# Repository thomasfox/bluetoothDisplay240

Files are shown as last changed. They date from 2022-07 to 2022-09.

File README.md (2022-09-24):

# bluetoothDisplay240

A bluetooth display for displaying speed, direction and a direction deviation bar while sailing.
Speed, direction and direction deviation measurements are transmitted via bluetooth, 
e.g. by a smartphone. The sum of component prices is about 100€.

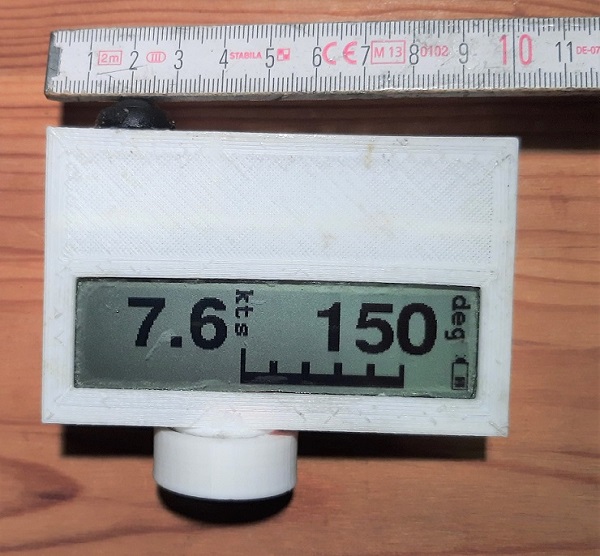
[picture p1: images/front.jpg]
Front view


This project contains
- The PCB and schematic of the circuit board in the [hardware](hardware) directory
- The code for the arduino compatible microcontroller on the circuit board in the [software](software) directory
- a Housing for 3D Printing  in the [housing](housing) directory
  (alternatively, you can use a commercial housing)

At the time of writing, material costs were approximately 100€. 
The electronics runs with 3.3V supply voltage, so it can be operated using a single LI-Ion battery.
The electronics draws about 15 mA supply current, so that with a 800 mAH battery, 
operation time is more than 50h without reloading.

## Electronics

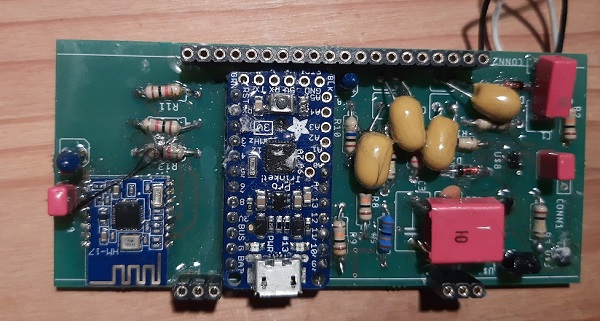
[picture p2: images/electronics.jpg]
Electronics


The main components of the ectronics are an arduino-compatible microcontroller board,
a graphical LCD Display with 240x64 pixels, and a Bluetooth Low Energy board. 
Discrete components are used for a soft-power latch and a battery watchdog. 

The quiescent current while being switched off is less than 1 μA,
so the standby-time for a 800 mA battery is only limited by the self-discharge time
of the battery.

The LCD display can be plugged in via socket rows. 
In my experience, not all socker rows provide a good contact to the LCD Display,
I had better experiences with the cheaper ones.

The arduino compatible board is soldered on using post rows, so that there is a small gap 
between the PCB and the arduino compatible board.

The press-button switch should only provide contact while pressed.
If a waterproof housing is wanted, the switch should be at least IP67 classed.

The battery charging circuit board in the BOM provides 1A of charging current.
I prefer a lower charging current of 250 mA, for which the R3 Resistor 
on the charging circuit board must be replaced by a 4k7 SMD resistor.
The charging PCB and the Arduino compatible board both use their own micro USB socket;
note that charging is not possible using the Arduino-compatible board USB socket, 
and programming is not possible using the charging board USB socket.

The current PCB design has a small flaw because the large foil condensators must lie on the PCB
rather than stand; but there is no explicit place reserved for that. 
So these condensators must be laid on top of other components, which worked for me.

The components needed are listed in the [Bill of Material (BOM)](hardware/bom.md). 
I obtained most of the components from the distributor [Reichelt](https://www.reichelt.de).
For your convenience, I have a public list there 
[https://www.reichelt.de/my/1939286](https://www.reichelt.de/my/1939286) 
containing the components marked in the BOM.
The HM 17 Bluetooth module was obtained from an ebay shop,
the non-marked resistors from a resistor assortment and the litz wire also from Reichelt.
Feel free to purchase the components where you want,
I do not earn anything if you purchase from Reichelt!

Then you need the PCB, I had mine made by [Aisler](https://aisler.net/), but again feel free to use another manufacturer.

Approximate prices at the time of writing were

| **Item** | **material** | **shipping** |
| --- | --- | --- |
| Reichelt List | 70€ | 6€ |
| HM17 | 11€ | 3€ |
| PCB | 13€ for a batch of 3 | - |

which adds up to about 100€ for one display.

### Assembly

You need a soldering iron with a small tip and soldering lead.
There are three SMD FET's on the PCB, which can be soldered with a soldering iron.
This can be a little tricky for an inexperienced solderer like me, but it worked in the end.
I'd recommend to solder the SMD FETs at the beginning, because then there is a 
Then, the film capacitors should be soldered at the end and with as much spare wire above the PCB as possible,
because they need to be bent in order to put the LCD display on top.

The battery holder should be connected to the charging board, 
which in turn should be connected to CONN1 using litz wire.
The push-Button switch should be connected to CONN2 also using litz wire.

You can consider to lacquer the board after all is finished and tested to improve water resistance. 
Be sure not to lacquer the pin rows, the lacquer tends to creep up in the pin holes.

## Software

You need to load the software onto the arduino compatible microcontroller board, e.g. using the Arduino IDE
and a micro USB cable. Make sure to select the correct board (Adafruit Trinket 3V) 
and the correct Programmer (USBtinyISP) in the Arduino IDE.

A good test is to try and upload a simple Arduino demo program (e.g. blink) onto the board 
before it is soldered in to make sure everything works as expected.

As the USB port on the microcontroller board is software-implemented,
new USB 3.0 ports typically lead to upload errors. 
The solution in my case was to use a cheap USB 2.0 hub between the PC and the microcontroller board.

To feed the display, I use my [Saillogger](https://github.com/thomasfox/saillogger) android app.

## Bluetooth Low Energy Protocol

The bluetooth low energy (BLE) transmission protocol is very simple: 
The feeding device writes the field identifier, a colon (:) and the value of the addressed field
to the one BLE characteristic offered by the device's BLE receiver. After that, the sending device needs to wait some time
(should be some 10 ms, I still need to find out how long) before sending the next value.

The field id is f1 for the velocity field, f2 for the direction field and f3 for the direction bar.
For the f1 and f2 fields, the value can be any short string containing the characters a-z, A-Z, 0-9 or .,:
(short meaning the value fits in the field's window in the display).
For the f3 field, the value needs to be an integer value between -100 and 100.
The character ';' should act as a field separator (I need to verify whether that works).

For the used characteristic, the service uuid is "0000ffe0-0000-1000-8000-00805f9b34fb"
and the characteristic uuid is "0000ffe1-0000-1000-8000-00805f9b34fb"

You can use  [Saillogger's BLE sender](https://github.com/thomasfox/saillogger/blob/master/app/src/main/java/com/github/thomasfox/saildata/sender/BleSender.java)
as a java/android code example for a bluetooth sender.

## Housing

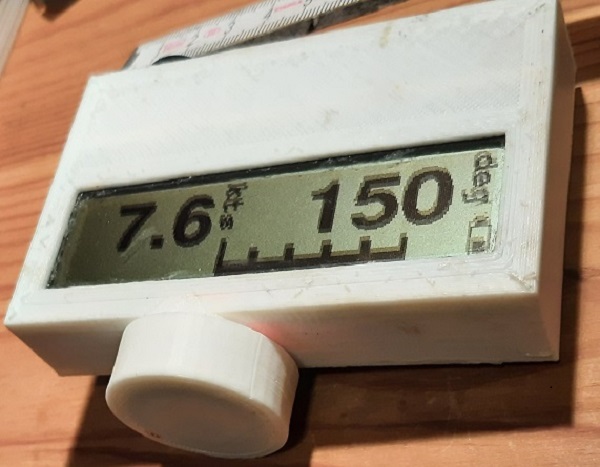
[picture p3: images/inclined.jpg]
Inclined


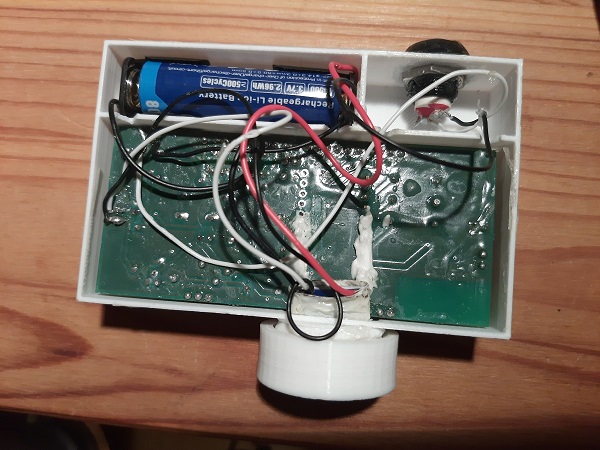
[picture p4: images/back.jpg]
Back


The Housing consists of the main housing, a lid which is glued to the main housing, 
and a screw-lid through which the two USB sockets can be accessed. 
They can be 3D printed, I used PLA as printing material.

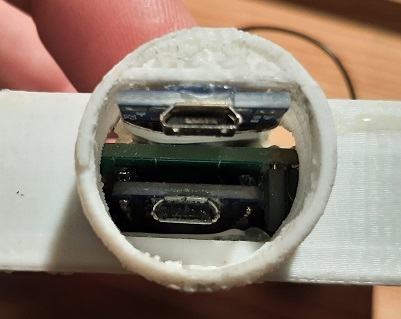
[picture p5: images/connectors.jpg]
Connectors


For a waterproof screw-lid, an o-ring is needed with an inner diameter of 20mm 
and a material diameter of 2mm.

The LCD Display is glued in the main housing, such that no water can enter between housing and Display.
Then the charging board is glued into the tube of the screw-lid, and the switch and battery holder 
are also glued into place.
Then the circuit board is connected to the LCD display, and the lid is glued an, 
also in such a way that no water can enter.

For gluing, I used pattex repair glue, which is transparent and stays flexible when cured, but any similar glue will do.

## Alternative Housing

I had some difficulties in getting my own housing really waterproof, so as an alternative
you can use a commercial housing. I used the 130x80x35mm FIBOX PC 100/35 LT Housing, 
which was available at the time of writing for €17 plus 5€ shipping from [Conrad](https://www.conrad.de).
The LCD needs to be glued to the transparent cover; I glued just the edges. 
Also a hole needs to be drilled for the push-button switch, which then also needs to be glued in.

## Questions?

Please open a [issue](../../issues) if you have any questions.

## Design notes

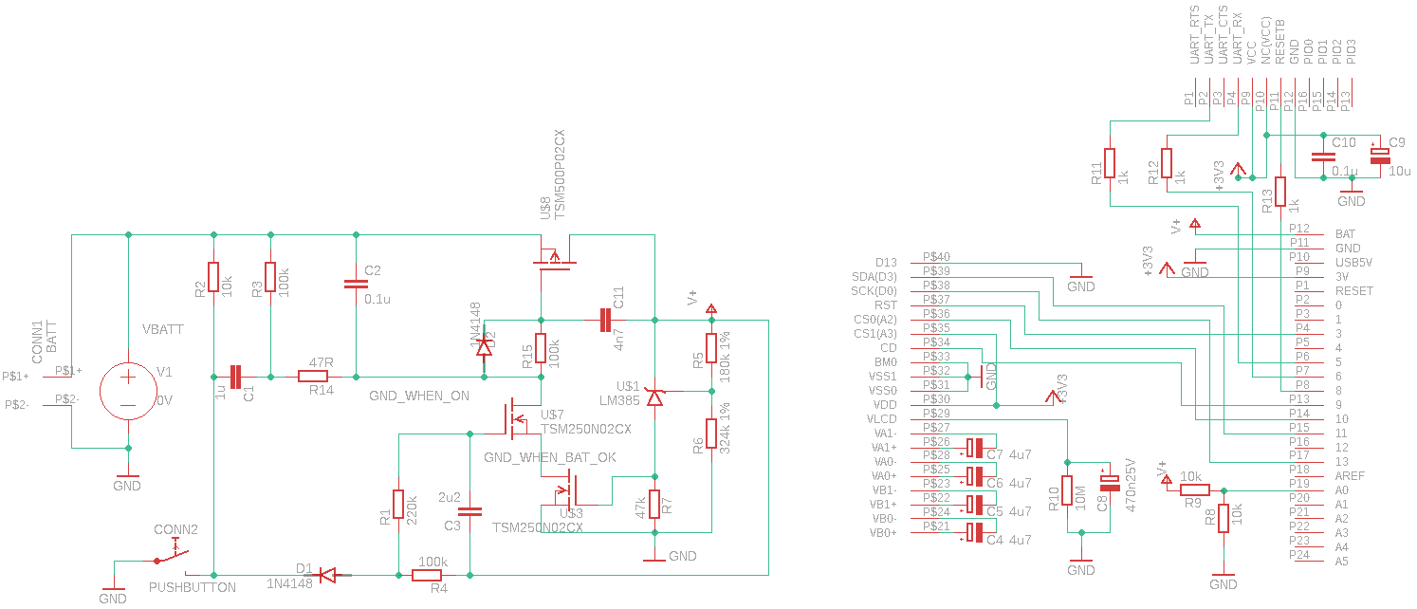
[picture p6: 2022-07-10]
hardware/BluetoothDisplay240Schematic.png

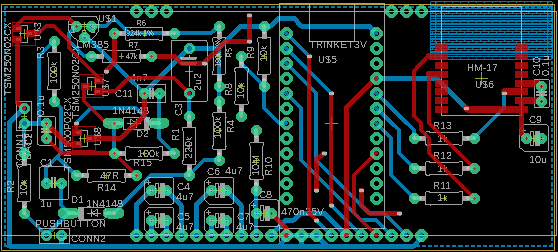
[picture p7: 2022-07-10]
hardware/BluetoothDisplay240Board.png

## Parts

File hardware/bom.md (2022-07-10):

| **Quantity** | **Value** | **Additional Info**  | **Name** | **Contained in Reichelt List** |
| ---| --- | --- | --- | --- |
| **Condensators** |
| 1 | 4n7 | 10V Ceramic | C11 | x |
| 2 | 0.1u | 10V Film | C2,C10 | x |
| 1 | 470n | 25V Tantal | C8 | x |
| 1 | 1u | 10V Film | C1 | x |
| 1 | 2.2u | 10V Film | C3 | x |
| 4 | 4.7u | 10V Tantal | C4,C5,C6,C7 | x |
| 1 | 10u | 10V Tantal | C9 | x |
| **Diodes** |
| 2 | 1N4148 | | D1,D2 | x |
| **Resisitors** |
| 1 | 47R | 1/4W 5% | R14 | |
| 3 | 1k | 1/4W 5% | R11,R12,R13 | |
| 3 | 10k | 1/4W 5% | R2,R8,R9 | |
| 1 | 47k | 1/4W 5% | R7 | |
| 3 | 100k | 1/4W 5% | R3,R4,R15 |  |
| 1 | 220k | 1/4W 5% | R1 | |
| 1 | 180k | 1/4W 1% | R5 | x |
| 1 | 324k | 1/4W 1% | R6 | x |
| 1 | 10M | 1/4W 5% | R10 | x |
| **Other** |
| 1 | | LM385Z | U$1 | x |
| 2 | | TSM250N02CX or TSM2302SMD | U$3, U$7 | x |
| 1 | | TSM500P02CX | U$8 | x |
| 1 | | DOGM240-6 | U$4 | x |
| 1 | | TRINKET3V | U$5 | x |
| 1 | | HM-17 Bluetooth Module | U$6 | |
| 1 | | Press-Button switch  | | x |
| **Charger Board** |
| 1 | | DEBO2 3.7LI 1.0A | | x |
| 1 | 4k7 | SMD Resistor 0603 100mW | | x |
| **Battery & Battery holder** |
| 1 | | Li-Ion Battery 3,7V  | | x |
| 1 | | Battery Holder | | x |
| **Socket rows** |
| 1 | | 20-Pin row 2,54mm | | x |
| 2 | | 3-Pin row 2,54mm | | x |
| **Pin rows (probably contained in Trinket3V)**  |
| 1 | | 7-pin 1row 2,54mm | | x |
| 1 | | 12-pin 1row 2,54mm  | | x |
| **wire** |
| 6 | | 15 cm litz wire | | |

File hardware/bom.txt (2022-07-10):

Part  Value       Device              Package      Description                          POPULARITY SPICEPREFIX
Condensators
1x 0.01u   C11
2x 0.1u    C2,C10
1x 470n25V C8
1x   1u    C1
1x 2.2u    C3
4x 4.7u    C4,C5,C6,C7
1x  10u    C9

Diodes
2x  1N4148 D1,D2

Resistors 1/4W 5%
1x    47R      R14
3x     1k      R11,R12,R13
3x    10k      R2,R8,R9
1x    47k      R7
3x   100k      R3,R4,R15
1x   220k      R1
1x    10M      R10

Resistors 1/4W 1%

1x   180k      R5
1x   324k      R6

U$1   LM385       LM385               TO92.PAC                                                                
U$3   TSM2302SMD  TSM2302SMD          SOT23                                                                   
U$4   DOGM240-6   DOGM240-6           LCD-DISPLAY  EA DOGM 240-6 LCD Display                                  
U$5   TRINKET3V   TRINKET3V           TRINKET3V                                                               
U$6   HM-17       HM-17               HM-17                                                                   
U$7   TSM2302SMD  TSM2302SMD          SOT23                                                                   
U$8   TSM500P02CX TSM500P02CX         SOT23                                                                   
1x Battery loader curcuit

Switches
1x Press-Button switch

Battery & Battery holder
1x Battery 3,7V
1x Battery Holder

Socket row
1 x 20Pin row
2x 6-pin row

cables
4 * 15 cm cable

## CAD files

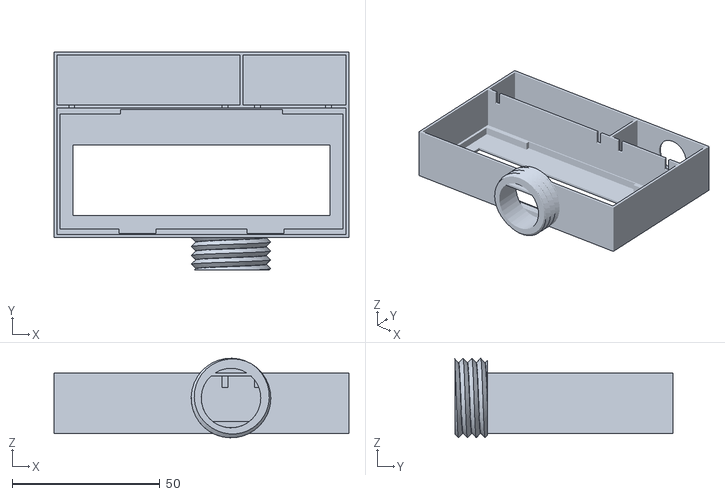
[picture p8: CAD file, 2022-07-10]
housing/SpeedDisplay240HousingMain.stl
100.0 x 74.0 x 27.0

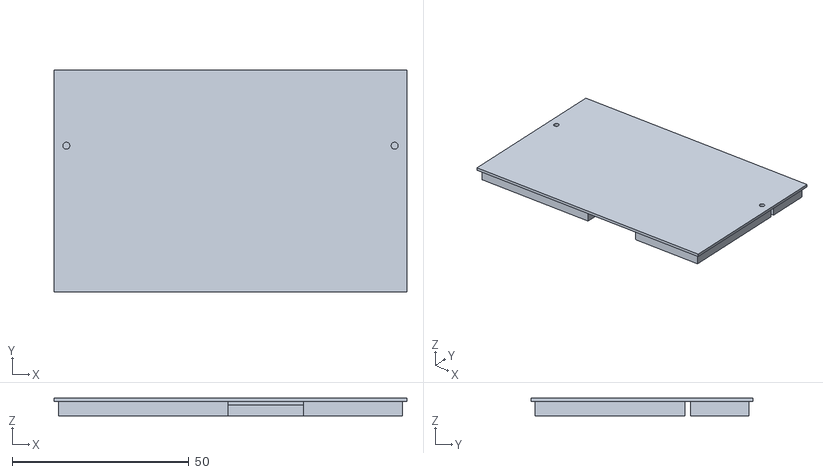
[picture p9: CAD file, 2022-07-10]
housing/SpeedDisplay240HousingLid.stl
100.0 x 63.0 x 5.00

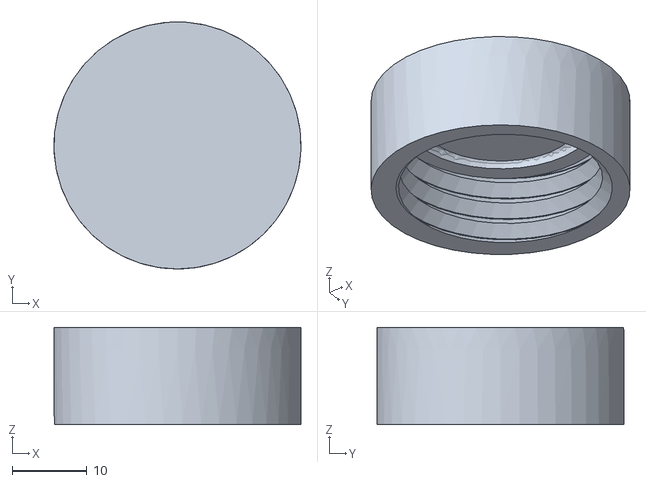
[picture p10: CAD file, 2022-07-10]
housing/SpeedDisplay240HousingScrewCap.stl
33.0 x 33.0 x 13.0

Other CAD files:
housing/SpeedDisplay240.FCStd

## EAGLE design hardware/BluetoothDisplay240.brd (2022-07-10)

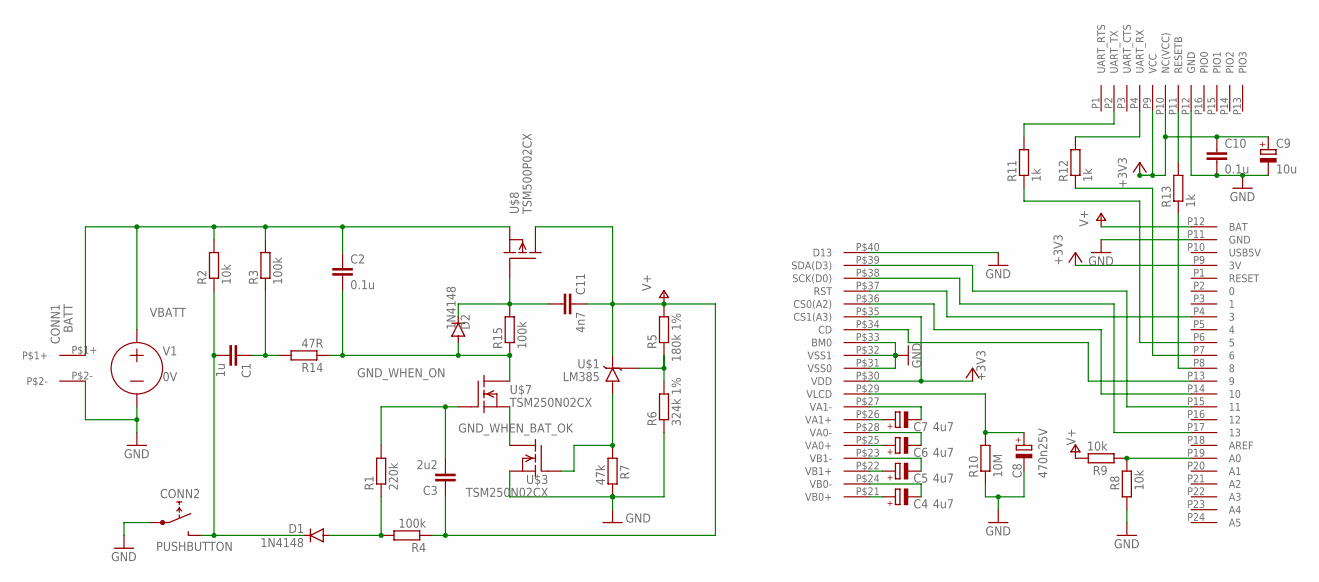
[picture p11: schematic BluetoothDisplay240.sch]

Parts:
C1: 1u; C025-060X050
C2: 0.1u; C025-030X050
C3: 2u2; C075-063X106
C4, C5, C6, C7: 4u7; B45181A
C8: 470n25V; B45181A
C9: 10u; B45181A
C10: 0.1u; C025-025X050
C11: 4n7; C025-030X050
CONN1: BATT; 2-PIN_CONN
CONN2: PUSHBUTTON; 2-PIN_CONN
D1, D2: 1N4148; DO35-7
R1: 220k; 0207/10
R2, R8, R9: 10k; 0207/10
R3, R4, R15: 100k; 0207/10
R5: 180k 1%; 0207/10
R6: 324k 1%; 0207/10
R7: 47k; 0207/10
R10: 10M; 0207/10
R11, R12, R13: 1k; 0207/10
R14: 47R; 0207/10
U$1: LM385; TO92.PAC
U$3, U$7: TSM250N02CX; SOT23
U$4: DOGM240-6; LCD-DISPLAY
U$5: TRINKET3V
U$6: HM-17
U$8: TSM500P02CX; SOT23

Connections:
+3V3: C9.+, C10.1, U$4.P$30 (VDD), U$4.P$35 (CS1(A3)), U$5.P9 (3V), U$6.P9 (VCC), U$6.P10 (NC(VCC))
BT_RES: R13.2, U$6.P11 (RESETB)
BT_RES1: R13.1, U$5.P8 (8)
BT_RX: R12.2, U$6.P4 (UART_RX)
BT_RX1: R12.1, U$5.P7 (6)
BT_TX: R11.2, U$6.P2 (UART_TX)
BT_TX1: R11.1, U$5.P6 (5)
CD_DISP: U$4.P$34 (CD), U$5.P13 (9)
CS_DISP: U$4.P$36 (CS0(A2)), U$5.P14 (10)
GND: C8.-, C9.-, C10.2, CONN1.P$2-, CONN2.P$1+ (1A), R6.1, R7.2, R8.1, R10.1, U$3.2 (S), U$4.P$31 (VSS0), U$4.P$32 (VSS1), U$4.P$33 (BM0), U$4.P$40 (D13), U$5.P11 (GND), U$6.P12 (GND)
GND_WHEN_BAT_OK: U$3.3 (D), U$7.2 (S)
GND_WHEN_ON: C2.2, D2.A, R14.1, R15.1, U$7.3 (D)
HIGH_WHEN_BAT_OK: R7.1, U$1.1 (GND), U$3.1 (G)
unnamed: C4.+, U$4.P$21 (VB0+)
unnamed: C1.1, R3.1, R14.2
unnamed: C4.-, U$4.P$24 (VB0-)
unnamed: C5.+, U$4.P$22 (VB1+)
unnamed: C5.-, U$4.P$23 (VB1-)
unnamed: C6.+, U$4.P$25 (VA0+)
unnamed: C6.-, U$4.P$28 (VA0-)
unnamed: C7.+, U$4.P$26 (VA1+)
unnamed: C7.-, U$4.P$27 (VA1-)
ON_CTL: C11.2, D2.C, R15.2, U$8.1 (G)
PUSH_GND: C1.2, CONN2.P$2- (A2), D1.C, R2.1
PUSH_GND_2: D1.A, R1.1, R4.2
RST_DISP: U$4.P$37 (RST), U$5.P4 (3)
SCK_DISP: U$4.P$38 (SCK(D0)), U$5.P17 (13)
SDA_DISP: U$4.P$39 (SDA(D3)), U$5.P15 (11)
SWITCH_STATE: C3.2, R1.2, U$7.1 (G)
V+: C3.1, C11.1, R4.1, R5.2, R9.2, U$1.2 (VOUT), U$5.P12 (BAT), U$8.3 (D)
V+LOW_SENSE: R5.1, R6.2, U$1.3 (REF)
V+_SENSE: R8.2, R9.1, U$5.P19 (A0)
VBATT: C2.1, CONN1.P$1+, R2.2, R3.2, U$8.2 (S)
VLCD: C8.+, R10.2, U$4.P$29 (VLCD)

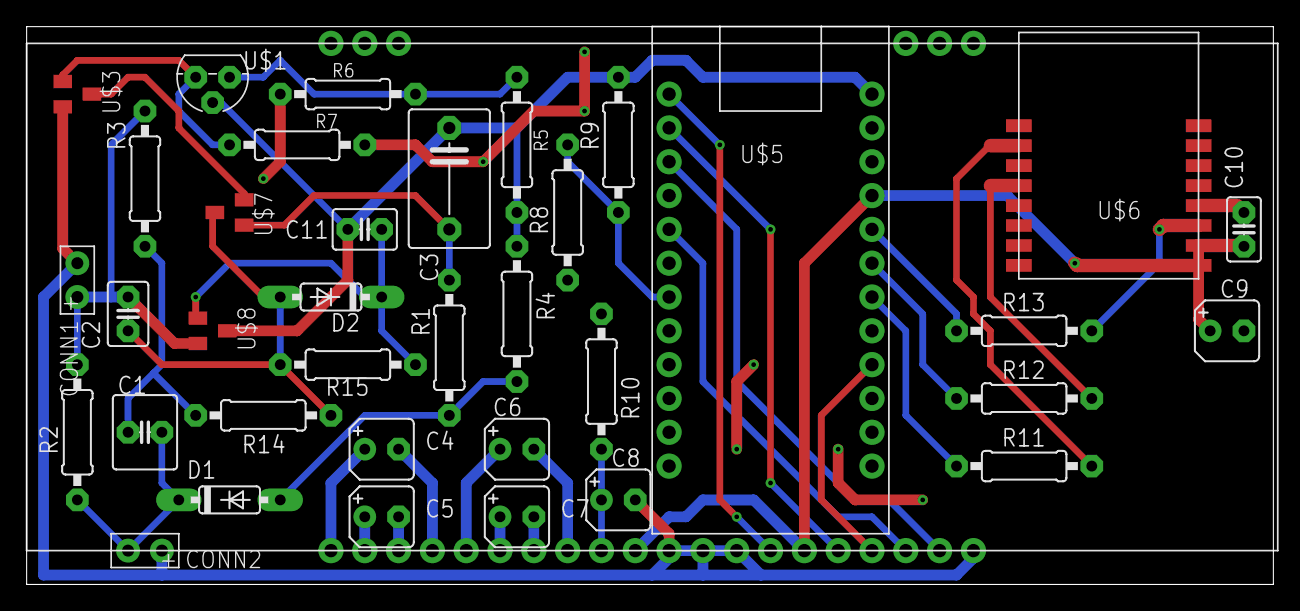
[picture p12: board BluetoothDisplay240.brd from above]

Board: 2 copper layers, 93.7 x 41.9 mm, 37 parts (0 on the bottom side), 34 nets.

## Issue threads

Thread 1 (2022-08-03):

reserve space for lying condensators

thomasfox, 2022-08-03:
The 2.2 µF and 1 µF film condensators need to be lying in order not to block the LCD.
Currently there is no space reserved for them, they need to be bent over other parts

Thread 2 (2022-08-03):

bigger holes for connectors

thomasfox, 2022-08-03:
The holes for connectors CONN! and CONN2 are too small for easily getting litz wire through

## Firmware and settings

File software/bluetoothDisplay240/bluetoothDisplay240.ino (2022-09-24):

/*
 * Copyright (c) 2022 Thomas Fox
 *
 * This file is free software; you can redistribute it and/or modify it
 * under the terms of the GNU General Public License version 2
 * as published by the Free Software Foundation.
 */
#include <Arduino.h>
#include <SoftwareSerial.h>
#include <SPI.h>
#include "DogDisplay.h"
#include "StringDisplay.h"
#include "gfxfont.h"
#include "FreeSansBold24pt7b.h"
#include "FieldConfiguration.h"

const uint8_t BLUETOOTH_BUFFER_SIZE = 30;

const GFXfont *gfxfont = &FreeSansBold24pt7b;

const uint8_t ktsBitmap[] PROGMEM = {
  0xE7, 0xE7, 0x76, 0x3E, 0x1E, 0x3E, 0xF6, 0xF6, 0x06, 0x07, 
  0x07, 0xE1, 0xF1, 0x30, 0x30, 0x30, 0x30, 0xF8, 0xF8, 0x30, 
  0x30, 0x30, 0x83, 0x87, 0x84, 0x00, 0x80, 0x80, 0x83, 0x03, 
  0x00, 0x00, 0x00, 0x1F, 0x7F, 0x61, 0x7E, 0x1F, 0x61, 0x7F, 
  0x7E, 0x00, 0x00, 0x00}; // created using gfxutils with font FreeMonoBold9pt7

const uint8_t degBitmap[] PROGMEM = {
  0x00, 0x00, 0x00, 0x00, 0xFC, 0xFE, 0xC7, 0x83, 0x83, 0xC7, 
  0xFE, 0xBC, 0x80, 0xC0, 0xC0, 0x00, 0x00, 0x00, 0x00, 0xE3, 
  0xF3, 0x19, 0xF9, 0xF9, 0x19, 0xF1, 0xE1, 0x01, 0x01, 0x01, 
  0x00, 0x00, 0x00, 0x00, 0x07, 0x8F, 0xC0, 0xCF, 0xCF, 0xCE, 
  0x87, 0x03, 0x00, 0x00, 0x00, 0x1F, 0x3F, 0x30, 0x30, 0x37, 
  0x3F, 0x39, 0x30, 0x30, 0x39, 0x7F, 0x7F, 0x00, 0x00, 0x00}; // created using gfxutils with font FreeMonoBold9pt7

const String VELOCITY_FIELD_PREFIX = "f1:";

const String DIRECTION_STRING_FIELD_PREFIX = "f2:";

const String DIRECTION_BAR_FIELD_PREFIX = "f3:";

const uint8_t FIELD_PREFIX_LENGTH = 3;

DogDisplay display;

SoftwareSerial bluetooth(5, 6); // RX, TX

char bluetoothReceiveBuffer[BLUETOOTH_BUFFER_SIZE];
 
uint8_t bluetoothReceiveBufferCursor = 0;

int16_t knots = 0;

StringFieldConfiguration velocityField;

StringFieldConfiguration directionStringField;

BarFieldConfiguration directionBarField;

void setup()
{
  bluetooth.begin(9600);
  display.initialize(10, MOSI, SCK, 9, 3);   //CS = 10, SI = MOSI ,CLK = SCK, CD = 9, RESET = 3

  velocityField.widthInPx = 107;
  velocityField.heightInBytes = 6;
  velocityField.gfxValueFont = gfxfont;
  velocityField.labelBitmap = &ktsBitmap[0];
  velocityField.labelBitmapWithInPx = 11;
  velocityField.labelBitmapHeightInBytes = 4;
  velocityField.display = display;
  
  directionStringField.xOffsetInPx = 130;
  directionStringField.widthInPx = 110;
  directionStringField.heightInBytes = 6;
  directionStringField.gfxValueFont = gfxfont;
  directionStringField.labelBitmap = &degBitmap[0];
  directionStringField.labelBitmapWithInPx = 15;
  directionStringField.labelBitmapHeightInBytes = 4;
  directionStringField.display = display;

  directionBarField.yOffsetInBytes = 6;
  directionBarField.widthInPx = 201;
  directionBarField.heightInBytes = 2;
  directionBarField.display = display;

  displayNoBluetoothConnection();
  
  velocityField.displayUnit();
  
  directionStringField.displayUnit();
  
  directionBarField.displayValue("0");
  
  bluetooth.write("AT+NAMELCDDISPLAY\r\n");
  delay(1000);
  receiveBluetooth();
  clearBluetoothReceiveBuffer();
}

//main loop
void loop()
{
  uint8_t batteryFull = batteryChargingState();
  display.drawBatterySymbol(230, 5, batteryFull);

  receiveBluetooth();
}

void receiveBluetooth()
{
  if (!bluetooth.available())
  {
    delay(100);
    return;
  }
  
  while (bluetooth.available())
  {
    char readFromBluetooth = bluetooth.read();
    //bluetooth.write(readFromBluetooth);
    if ((readFromBluetooth < '0' || readFromBluetooth > '9')
        && (readFromBluetooth < 'a' || readFromBluetooth > 'z')
        && (readFromBluetooth < 'A' || readFromBluetooth > 'Z')
        && readFromBluetooth!='.' 
        && readFromBluetooth!='-' 
        && readFromBluetooth!=';'
        && readFromBluetooth!=':')
    {
      // ignore all unknown characters
      continue;
    }
    if (readFromBluetooth == ';')
    {
      readFromBluetooth='\0';
    }
    bluetoothReceiveBuffer[bluetoothReceiveBufferCursor]=readFromBluetooth;
    String toDisplay = bluetoothReceiveBuffer;
    if (readFromBluetooth == '\0' || bluetoothReceiveBufferCursor >= BLUETOOTH_BUFFER_SIZE - 1)
    {
      toDisplay = bluetoothReceiveBuffer;
      determineFieldAndDisplayString(toDisplay);
      clearBluetoothReceiveBuffer();
    }
    else
    {
      bluetoothReceiveBufferCursor++;
    }
  }
  //bluetooth.write(bluetoothReceiveBuffer);
}

void clearBluetoothReceiveBuffer() 
{
  bluetoothReceiveBufferCursor = 0;
  for (uint8_t i = 0; i < BLUETOOTH_BUFFER_SIZE; i++)
  {
    bluetoothReceiveBuffer[i] = '\0';
  }
}

/**
 * Displays a prefixed String.
 * 
 * The field to display the value in is determined by the prefix, which should be any of the constants
 * <code>VELOCITY_FIELD_PREFIX</code>, <code>DIRECTION_STRING_FIELD_PREFIX</code>. 
 * or <code>DIRECTION_BAR_FIELD_PREFIX</code>.
 * 
 * The displayed value is then the passed String with the prefix removed.
 * If no prefix is recognized, the passed String is displayed as is in the directionStringField.
 * 
 * @param prefixedString the string to be displayed, consisting of a prefix for field selection
 *        and the value to be displayed. 
 */
void determineFieldAndDisplayString(String prefixedString)
{
  // Serial.print("prefixedString: " + prefixedString + "\r\n");
  if (prefixedString.startsWith(VELOCITY_FIELD_PREFIX)) 
  {
    velocityField.displayValue(prefixedString.substring(FIELD_PREFIX_LENGTH));
  }
  else if (prefixedString.startsWith(DIRECTION_STRING_FIELD_PREFIX))
  {
    directionStringField.displayValue(prefixedString.substring(FIELD_PREFIX_LENGTH));
  }
  else if (prefixedString.startsWith(DIRECTION_BAR_FIELD_PREFIX))
  {
    directionBarField.displayValue(prefixedString.substring(FIELD_PREFIX_LENGTH));
  }
//  else 
//  {
//    directionStringField.displayValue(prefixedString);
//  }
}

/**
 * Displays to the user that there is currently no bluetooth connection.
 * 
 * For this, the velocity field and the direction String field are used to display "No Conn"
 */
void displayNoBluetoothConnection()
{
  velocityField.displayValue("No");
  directionStringField.displayValue("Con");
}

/**
 * Returns the charging state of the battery.
 * 
 * @return 0 if the battery empty (device will switch off any moment), 
 *         255 if the battery is completely full,
 *         or a value in between describing how full the battery is.
 */
uint8_t batteryChargingState()
{
  // Battery charging state is read from analog channel 0. This input reads half the battery voltage.
  // The reference Voltage of 3.3V is equivalent to a reading of 1024.
  int16_t batteryAnalogRead = analogRead(0);

  // Battery charging state calculation
  // I/O conversion seems to become unlinear below approx 3.6V Battery voltage
  // from experiment: 4.1V = reading of 650, 3.5 V = reading of 570, difference is 70
  int16_t batteryAnalogReadAboveEmpty = batteryAnalogRead - 570;
  if (batteryAnalogReadAboveEmpty < 0)
  {
     batteryAnalogReadAboveEmpty = 0;
  }
  if (batteryAnalogReadAboveEmpty > 70)
  {
     batteryAnalogReadAboveEmpty = 70;
  }
  return (uint8_t)(batteryAnalogReadAboveEmpty*255/70);
}

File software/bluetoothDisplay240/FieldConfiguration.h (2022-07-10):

/*
 * Copyright (c) 2022 Thomas Fox
 *
 * This file is free software; you can redistribute it and/or modify it
 * under the terms of the GNU General Public License version 2
 * as published by the Free Software Foundation.
 */
#ifndef FIELD_CONFIGURATION_H
#define FIELD_CONFIGURATION_H

#include <gfxfont.h>

#include "DogDisplay.h"

// A StringFieldConfiguration displays a value on the display as String
// It occupies a rectangle on the sceen defined by xOffset, yOffset, width and height
// It contains a font to display the value
// It has a label (e.g. for displaying the name or the unit of the value), which is always displayed at the right of the field, using a bitmap
class StringFieldConfiguration
{
  public:
  String unit;                // the text to display as the unit of the quantity in the field
  uint16_t xOffsetInPx = 0;   // the X distance in pixel from display start to the start of the field, 0 if the field starts right where the display starts
  uint8_t yOffsetInBytes = 0; // the Y distance in bytes (8 pixel) from display start to the start of the field, 0 if the field starts right where the display starts
  uint16_t widthInPx;         // the X dimension of the field in pixel
  uint8_t heightInBytes;      // the Y dimension of the field in bytes (8 px)
  GFXfont *gfxValueFont;      // the font used to display the value of the field
  uint8_t labelValueXDistanceInPx = 4; // Distance between the label and the displayed value, in x Direction, in px
  uint8_t labelBitmapWithInPx;         // the with of the label bitmap in px
  uint8_t labelBitmapHeightInBytes;    // the height of the label bitmap in Bytes (== height in px / 8)
  const uint8_t *labelBitmap;          // the bitmap containing the label (e.g containing the unit) of the field, as dog type bitmap (first row followed by second row ...)
  DogDisplay display;                  // the display where the field is displayed on
  
  void displayValue(String toDisplay); // displays the passed String in the field
  void displayUnit();                  // displays the unit bitmap of the field 
};

// A BarFieldConfiguration displays a value on the display as a bar
// It occupies a rectangle on the sceen defined by xOffset, yOffset, width and height=16px
class BarFieldConfiguration
{
  public:
  String unit;                // the text to display as the unit of the quantity in the field
  uint16_t xOffsetInPx = 0;   // the X distance in pixel from display start to the start of the field, 0 if the field starts right where the display starts
  uint8_t yOffsetInBytes = 0; // the Y distance in bytes (8 pixel) from display start to the start of the field, 0 if the field starts right where the display starts
  uint16_t widthInPx = 201;   // the X dimension of the field in pixel
  uint8_t heightInBytes = 2;  // the Y dimension of the field in bytes (i.e. 8 px)
  boolean additionalZeroExtension = true; // whether to use another y byte at the zero mark to extend the zero mark upwards;
  DogDisplay display;         // the display where the field is displayed on
  
  void displayValue(String toDisplay); // parses the passed String as int and displays the parsed value on the bar graph. Negative values can be displayed as well.

  private:
  const int16_t ZERO_BAR_MAX_X = 2;                                           // how far the zero bar in the graph extends in x direction
  void displayYSegment(int16_t startX, int16_t endX, uint8_t yOffsetInBytes); // displays a y segment (8 px high)of the graph
  void displayZeroExtension(int16_t xRelativeToMiddleX);                      // display the y segment of the graph belonging to the elongated zero bar
  int16_t getMiddleX();                                                       // returns the x coordinate of the pixel in the middle of the field rectangle
};

#endif

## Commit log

2022-07-10 version 1.0.0 hardware and software
    [BluetoothDisplay240.brd, BluetoothDisplay240.sch, SpeedDisplay240.FCStd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]
2022-09-24 correct battery scale; display overflowing incomplete BLE buffer
    [bluetoothDisplay240.ino]
